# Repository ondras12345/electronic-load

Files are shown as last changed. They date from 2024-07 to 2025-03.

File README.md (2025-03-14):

# Electronic load
This repository contains hardware designs and firmware for my electronic load.

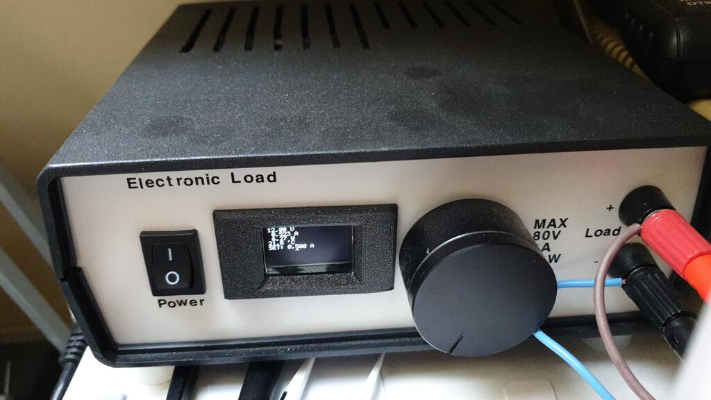
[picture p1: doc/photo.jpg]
DIY digitally controlled electronic load


## Hardware
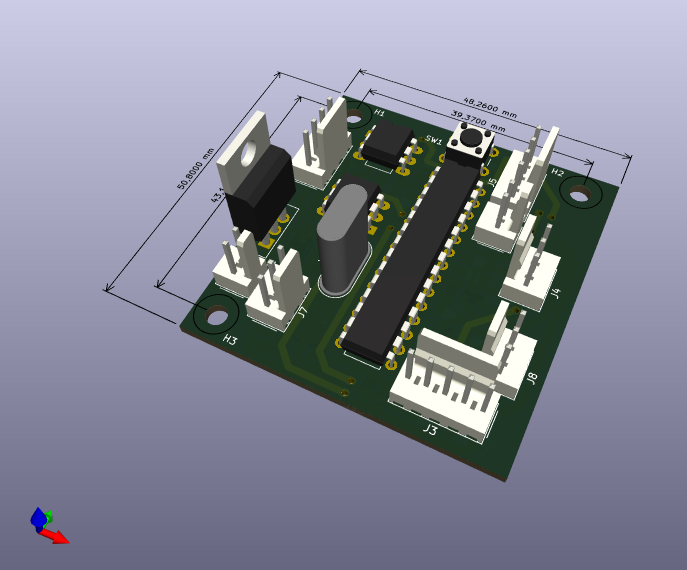
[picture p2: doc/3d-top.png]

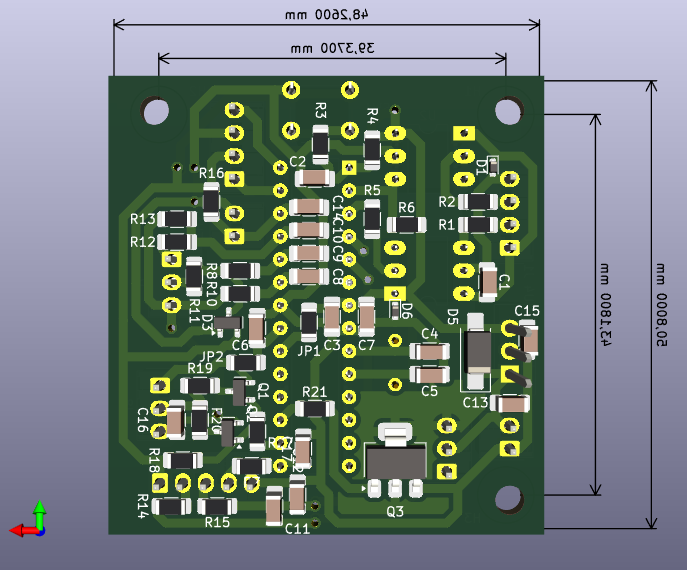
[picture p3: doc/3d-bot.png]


This project is based on an analog electronic load PCB from Aliexpress:
XHDZ-FZ-2g.
Originally, I just put it in a box and used it as-is with a 10-turn
potentiometer. However, then the pot failed, and I decided to upgrade it with
digital control. The control loop is still analog utilising the original
circuitry, but the reference signal is generated by a microcontroller instead
of the potentiometer.

My `electronic-load-controller` PCB contains an ATmega8 microcontroller,
a PWM DAC to generate the reference voltage, UART optoisolators for remote
control, and circuitry for measuring the load voltage and current.
It connects to the analog PCB via the original connectors with just one wire
needing to be soldered to a non-standard pad on the board.

The user interface consists of an SSD1306 OLED display and a rotary encoder.

Space for improvement: I didn't spend much time designing the user interface
and as a result, I had to use a small font that is hard to read from a
distance.

## Software
The firmware on the ATmega microcontroller performs several functions.
It measures the voltage across the load, the load current, calculates the
power loss and implements over-power protection, monitors the heatsink
temperature and controls the cooling fan.
It uses the DAC to generate the current setpoint signal for the analog board
based on the value set by the user via the rotary encoder,
and it implements a SCPI interface on the serial port for remote control
capability.

### SCPI commands
A text-based remote control interface is available on the serial port (9600
baud, 8N1).

The following table explains the individual command (`v` is a placeholder for
an integer argument).

| command | description |
|:---:|:---|
| `ISET v` | Set load current. E.g. `ISET 1000` sets the current to 1A. |
| `ISET?` | Get load current setpoint value in mA. |
| `IGAIN v` | Settings: set conversion coefficient for current measurement. |
| `IGAIN?` | Settings: get `IGAIN` value. |
| `VGAIN v` | Settings: set conversion coefficient for voltage measurement. |
| `VGAIN?` | Settings: get `VGAIN` value. |
| `SPGAIN v` | Settings: set conversion coefficient for current setpoint. |
| `SPGAIN?` | Settings: get `SPGAIN` value. |
| `SPOFF v` | Settings: set conversion offset for current setpoint. |
| `SPOFF?` | Settings: get `SPOFF` value. |
| `DUTY?` | Get PWM DAC duty cycle value. Useful for debugging. |
| `I?` | Get measured current in A. |
| `V?` | Get measured voltage in V. |
| `P?` | Get measured power in W. |
| `TEMP?` | Get heatsink temperature in degrees C. |
| `*BOOTLOADER` | Jump to bootloader to allow updating firmware. |
| `*SAV` | Save settings to EEPROM. |
| `*RST` | Reset the microcontroller. |

### Calibration
Calibration is performed using SCPI commands on the serial interface.
The goal is to make the load current and voltage readings accurate
and to make the current setpoint match the actual load current.

TODO document calibration procedure.

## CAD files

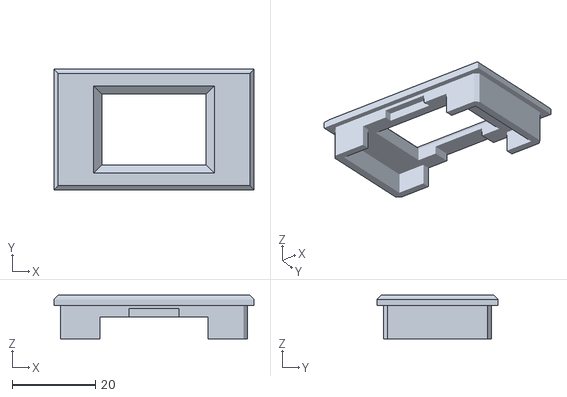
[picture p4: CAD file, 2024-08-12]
display-bracket-Part.stl
48.0 x 29.0 x 10.5

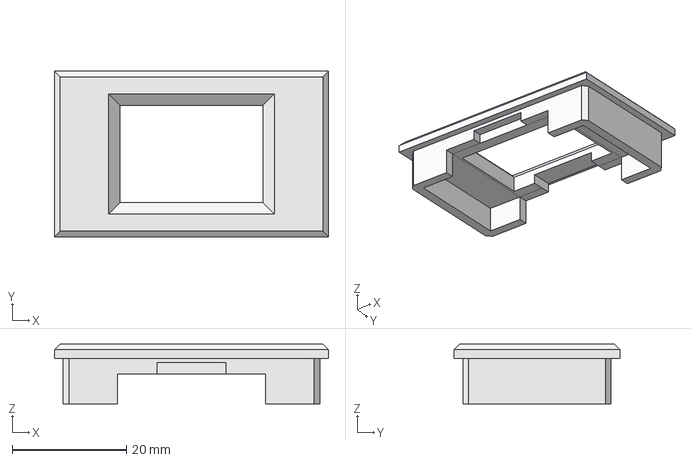
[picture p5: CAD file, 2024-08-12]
display-bracket.FCStd
48.0 x 29.0 x 10.5 mm

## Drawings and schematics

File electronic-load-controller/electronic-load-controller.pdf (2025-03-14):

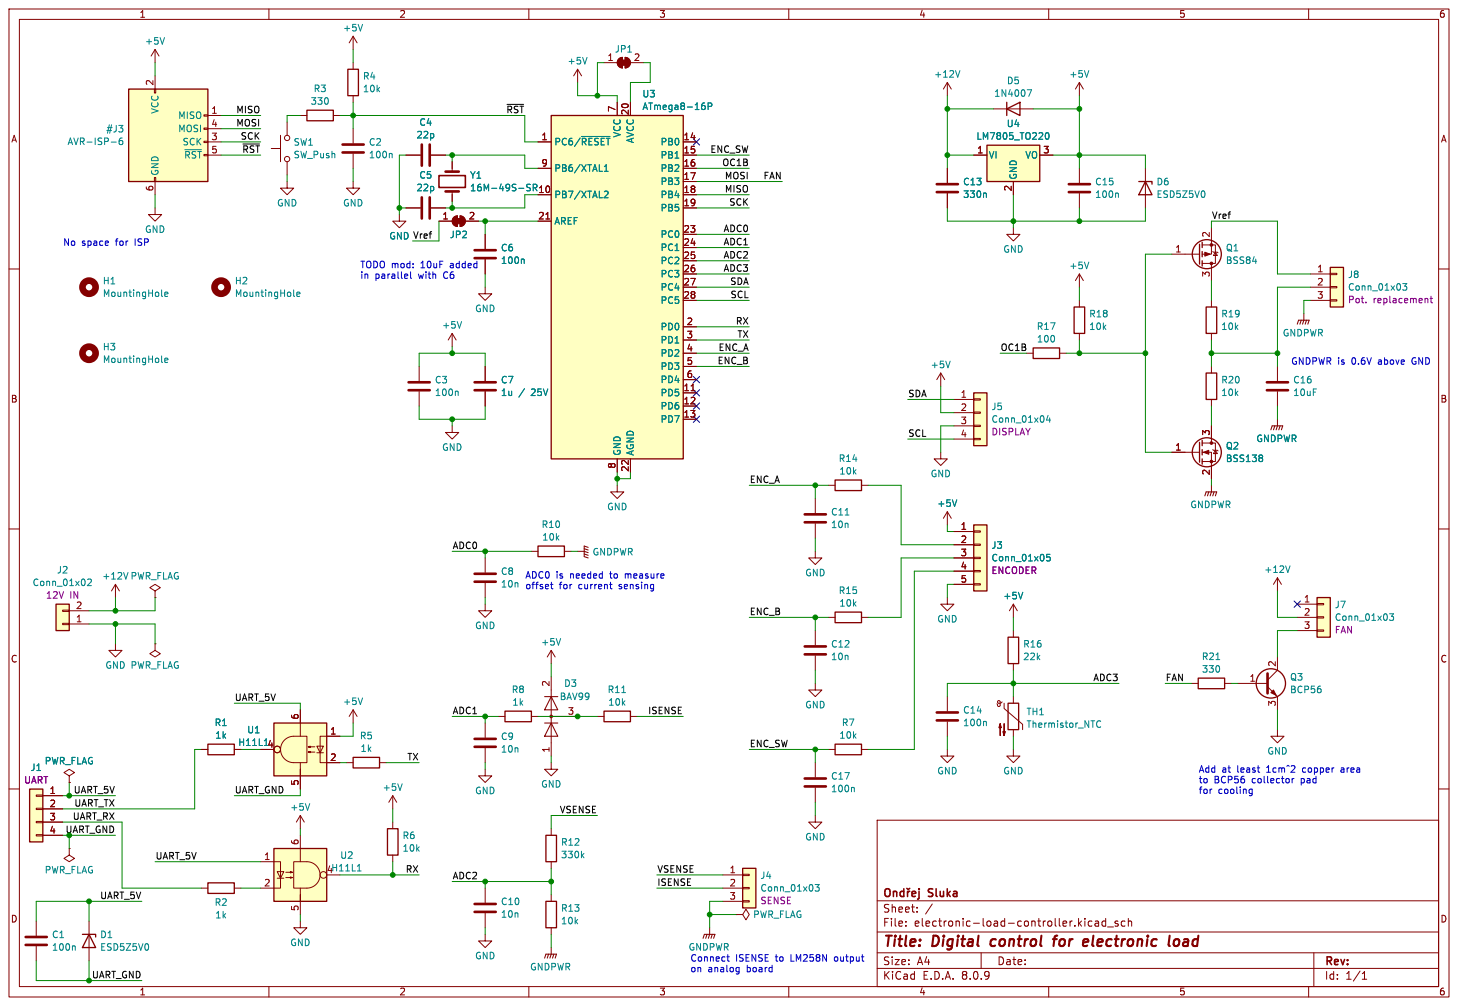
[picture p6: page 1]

2 SCK 3 MOSI 4 ~{RST}5 GND

SDA MISO MOSI SCK

File: electronic-load-controller.kicad_sch Sheet: / þÿOndYej Sluka

Id: 1/1 Title: Digital control for electronic load

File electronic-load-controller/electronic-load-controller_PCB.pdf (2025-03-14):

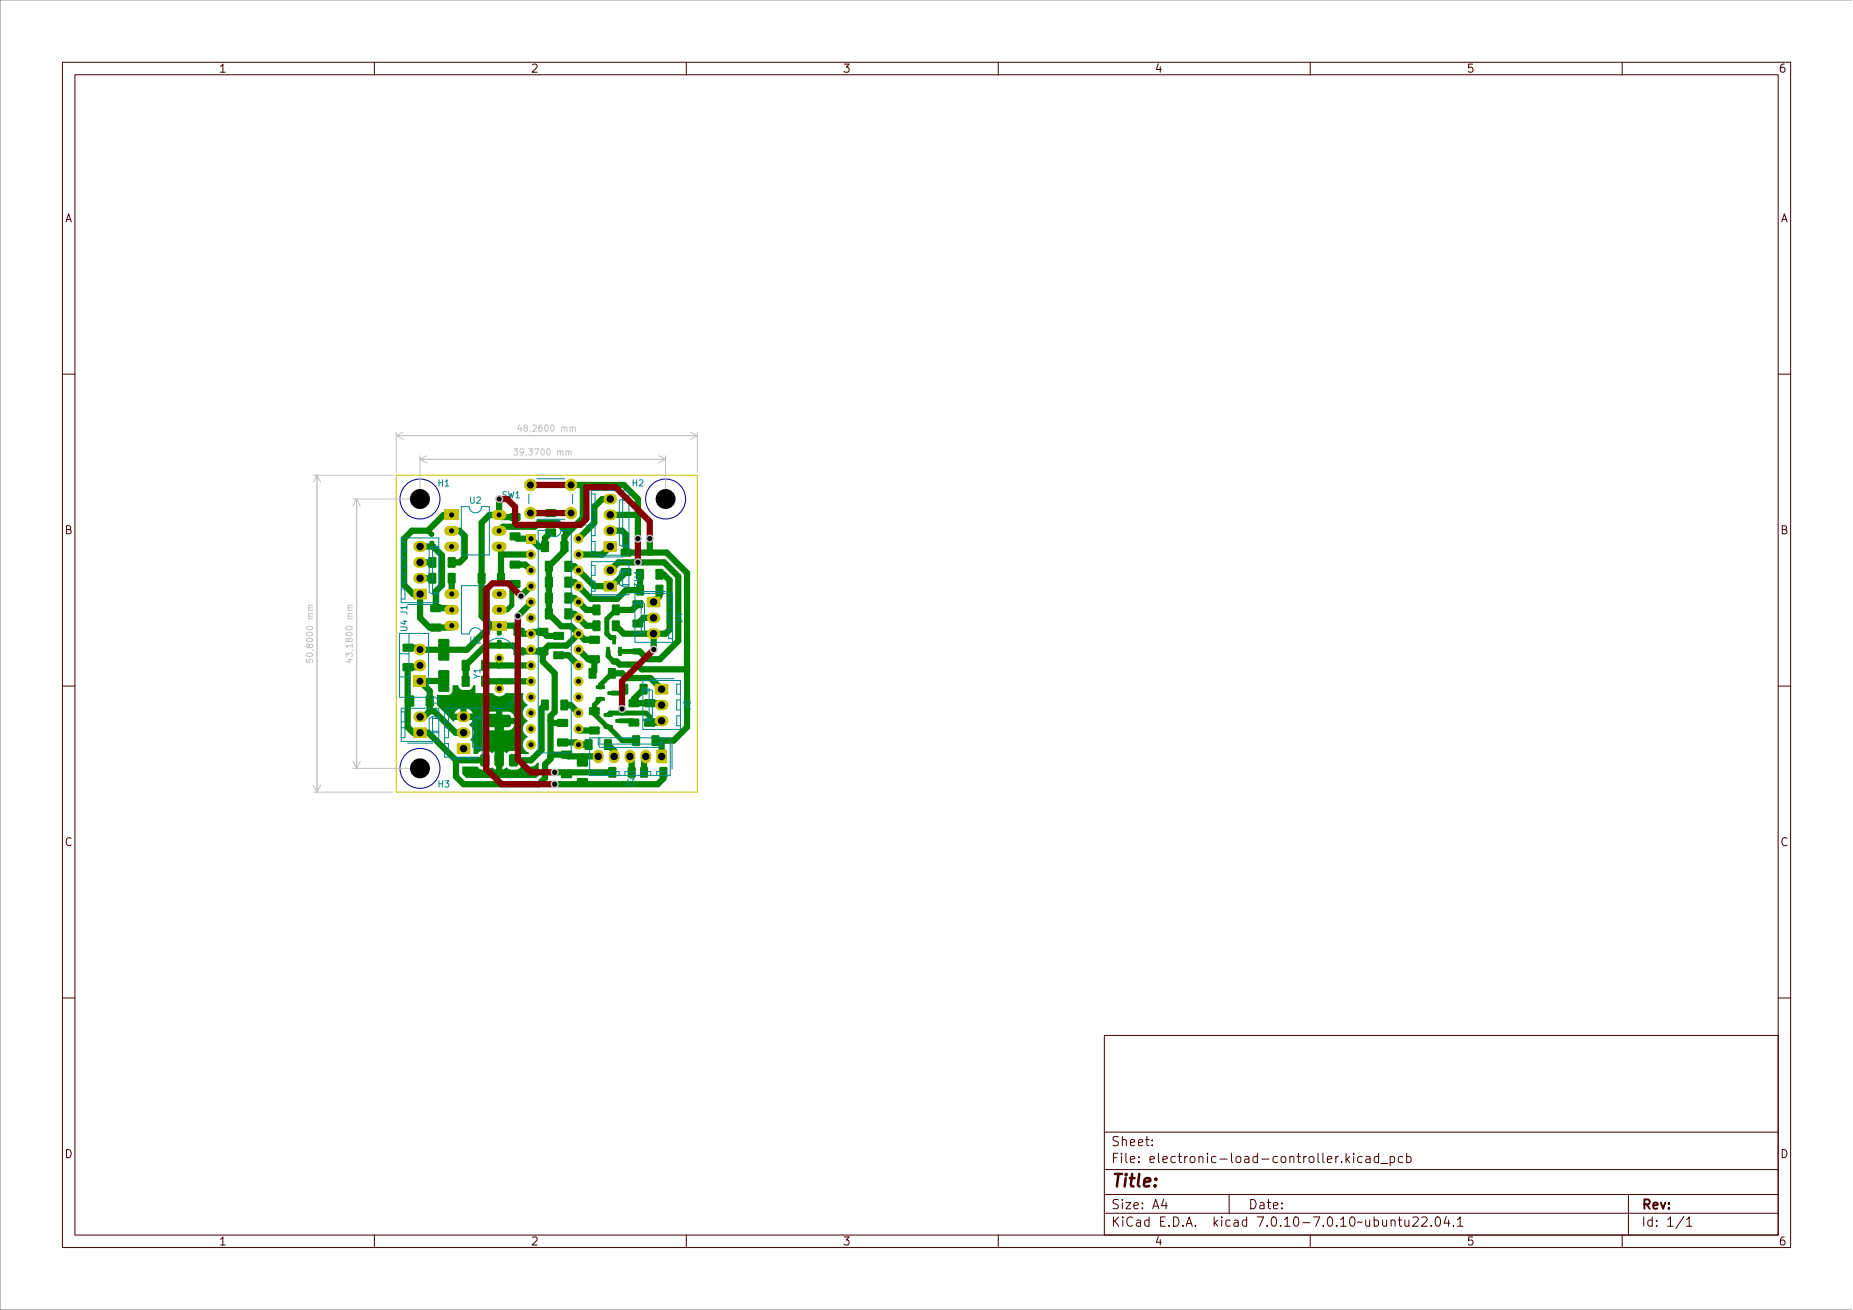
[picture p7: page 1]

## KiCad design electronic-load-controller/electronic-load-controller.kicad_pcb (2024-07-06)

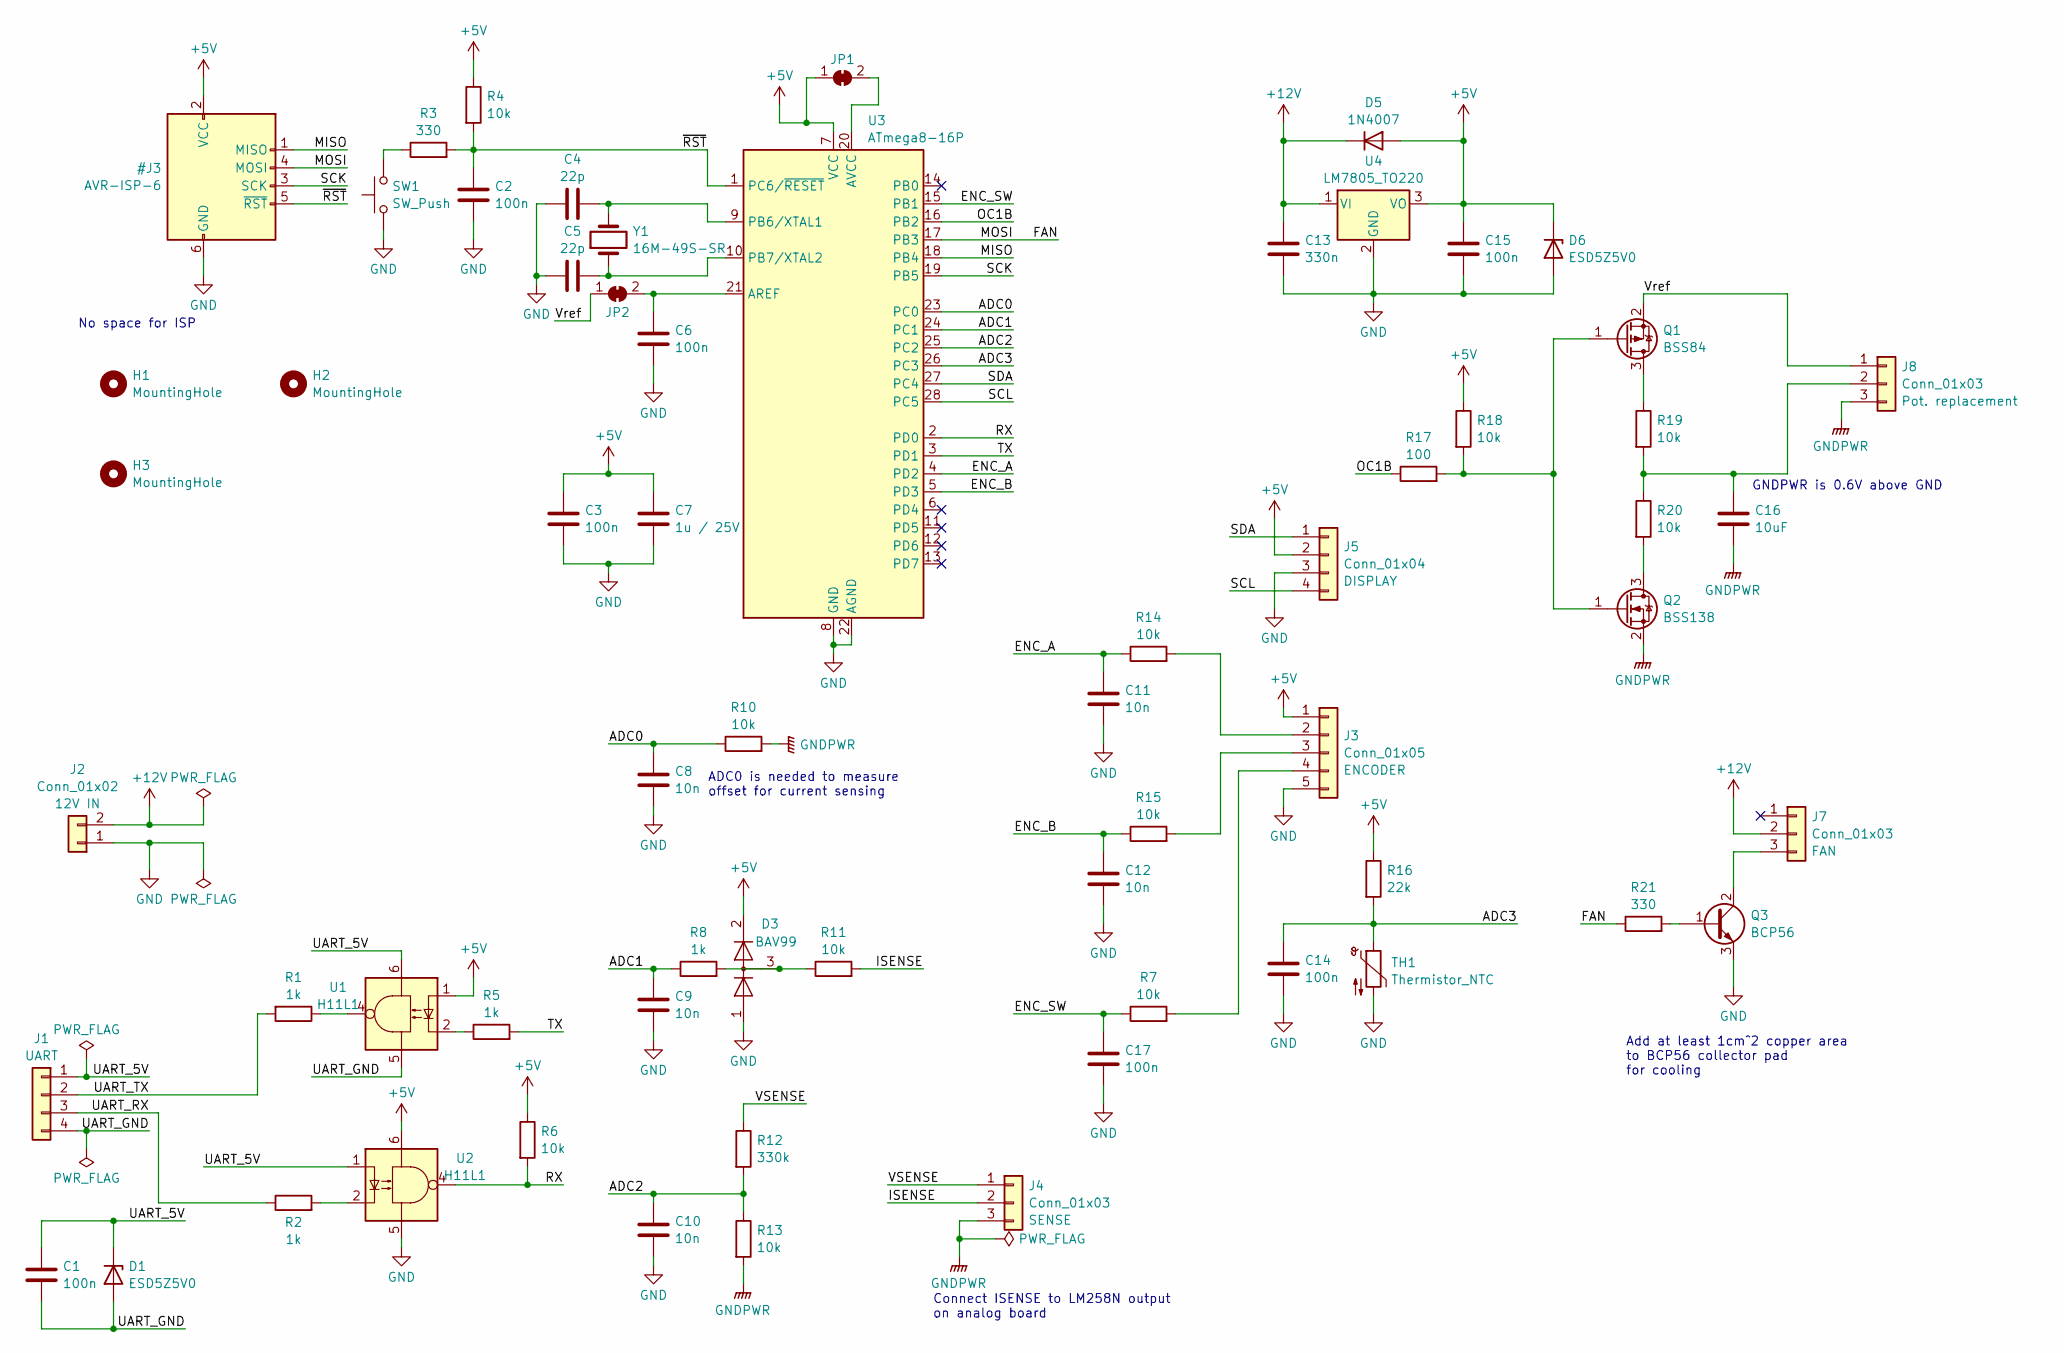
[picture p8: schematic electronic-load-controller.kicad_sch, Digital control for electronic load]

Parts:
C1, C2, C3, C6, C14, C15, C17: 100n; C_1206_3216Metric_Pad1.33x1.80mm_HandSolder
C4, C5: 22p; C_1206_3216Metric_Pad1.33x1.80mm_HandSolder
C7: 1u / 25V; C_1206_3216Metric_Pad1.33x1.80mm_HandSolder
C8, C9, C10, C11, C12: 10n; C_1206_3216Metric_Pad1.33x1.80mm_HandSolder
C13: 330n; C_1206_3216Metric_Pad1.33x1.80mm_HandSolder
C16: 10uF; C_1206_3216Metric_Pad1.33x1.80mm_HandSolder
D1, D6: ESD5Z5V0; D_SOD-523
D3: BAV99; SOT-23
D5: 1N4007; D_SMA_Handsoldering
H1, H2, H3: MountingHole; MountingHole_3.2mm_M3
J1, J5: Conn_01x04; Molex_KK-254_AE-6410-04A_1x04_P2.54mm_Vertical
J2: Conn_01x02; Molex_KK-254_AE-6410-02A_1x02_P2.54mm_Vertical
J3: Conn_01x05; Molex_KK-254_AE-6410-05A_1x05_P2.54mm_Vertical
J4, J7, J8: Conn_01x03; Molex_KK-254_AE-6410-03A_1x03_P2.54mm_Vertical
JP1, JP2: SolderJumper_2_Bridged; R_1206_3216Metric_Pad1.30x1.75mm_HandSolder
Q1: BSS84; SOT-23
Q2: BSS138; SOT-23
Q3: BCP56; SOT-223-3_TabPin2
R1, R2, R5, R8: 1k; R_1206_3216Metric_Pad1.30x1.75mm_HandSolder
R3, R21: 330; R_1206_3216Metric_Pad1.30x1.75mm_HandSolder
R4, R6, R7, R10, R11, R13, R14, R15, R18, R19, R20: 10k; R_1206_3216Metric_Pad1.30x1.75mm_HandSolder
R12: 330k; R_1206_3216Metric_Pad1.30x1.75mm_HandSolder
R16: 22k; R_1206_3216Metric_Pad1.30x1.75mm_HandSolder
R17: 100; R_1206_3216Metric_Pad1.30x1.75mm_HandSolder
SW1: SW_Push; SW_PUSH_6mm_H4.3mm
TH1: Thermistor_NTC; Molex_KK-254_AE-6410-02A_1x02_P2.54mm_Vertical
U1, U2: H11L1; DIP-6_W7.62mm_LongPads
U3: ATmega8-16P; DIP-28_W7.62mm
U4: LM7805_TO220; TO-220-3_Vertical
Y1: 16M-49S-SR; Crystal_HC49-U_Vertical

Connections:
+12V: C13.1, D5.1 (K), J2.2, J7.2, U4.1 (VI)
/ADC0: C8.1, R10.1, U3.23 (PC0)
/ADC1: C9.1, R8.1, U3.24 (PC1)
/ADC2: C10.1, R12.2, R13.1, U3.25 (PC2)
/ADC3: C14.1, R16.2, TH1.1, U3.26 (PC3)
/ENC_A: C11.1, R14.1, U3.4 (PD2)
/ENC_B: C12.1, R15.1, U3.5 (PD3)
/ENC_SW: C17.1, R7.1, U3.15 (PB1)
/ISENSE: J4.2, R11.2
/OC1B: R17.1, U3.16 (PB2)
/RX: R6.2, U2.4, U3.2 (PD0)
/SCL: J5.4, U3.28 (PC5)
/SDA: J5.1, U3.27 (PC4)
/TX: R5.2, U3.3 (PD1)
/UART_5V: C1.1, D1.1 (K), J1.1, U1.6, U2.1
/UART_GND: C1.2, D1.2 (A), J1.4, U1.5
/UART_RX: J1.3, R2.1
/UART_TX: J1.2, R1.2
/VSENSE: J4.1, R12.1
/Vref: J8.1, JP2.1 (A), Q1.2 (S)
GNDPWR: C16.2, J4.3, J8.3, Q2.2 (S), R10.2, R13.2
unnamed: D3.3 (K), R8.2, R11.1
unnamed: J3.2, R14.2
unnamed: J3.3, R15.2
unnamed: J3.4, R7.2
unnamed: J7.3, Q3.2 (C), Q3.4 (C)
unnamed: C16.1, J8.2, R19.2, R20.1
unnamed: JP1.2 (B), U3.20 (AVCC)
unnamed: C6.1, JP2.2 (B), U3.21 (AREF)
unnamed: Q1.3 (D), R19.1
unnamed: Q1.1 (G), Q2.1 (G), R17.2, R18.2
unnamed: Q2.3 (D), R20.2
unnamed: Q3.1 (B), R21.2
unnamed: R1.1, U1.4
unnamed: R2.2, U2.2
unnamed: R3.1, SW1.2
unnamed: R5.1, U1.2
unnamed: C4.2, U3.9 (PB6/XTAL1), Y1.2
unnamed: C5.2, U3.10 (PB7/XTAL2), Y1.1

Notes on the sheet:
Connect ISENSE to LM258N output on analog board
Add at least 1cm^2 copper area to BCP56 collector pad for cooling
No space for ISP
ADC0 is needed to measure offset for current sensing
GNDPWR is 0.6V above GND

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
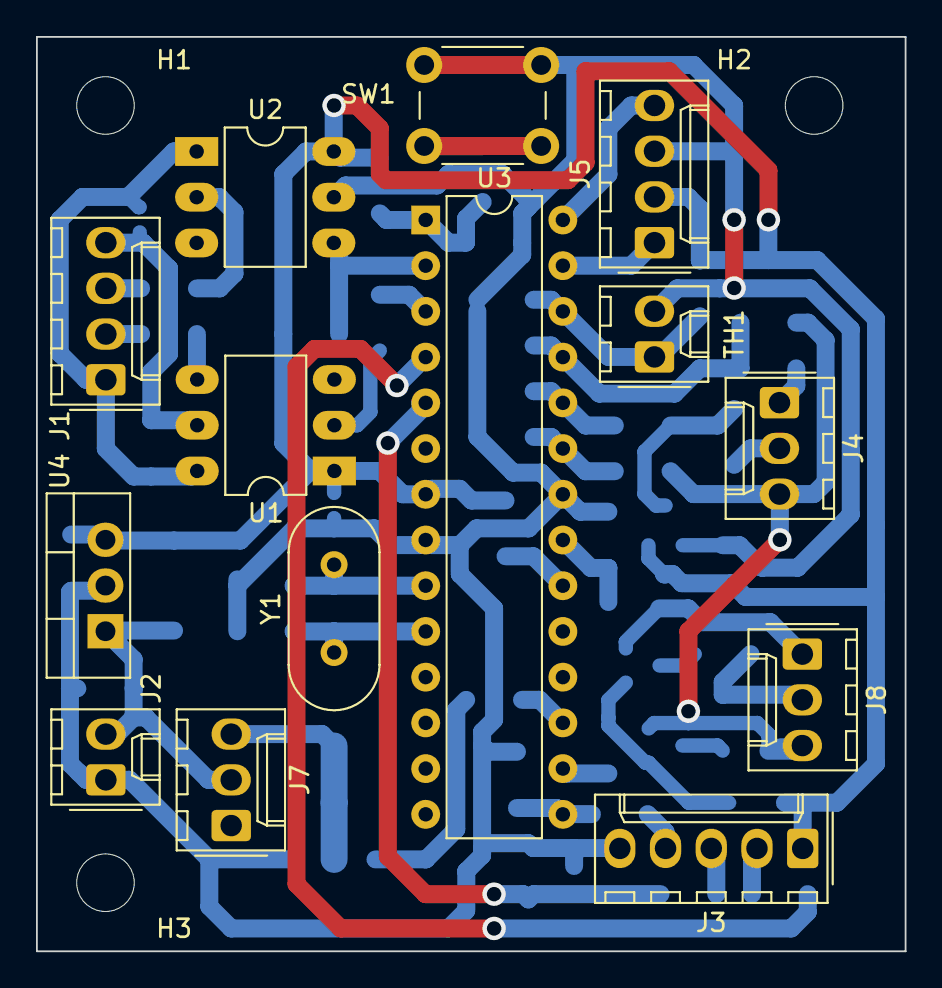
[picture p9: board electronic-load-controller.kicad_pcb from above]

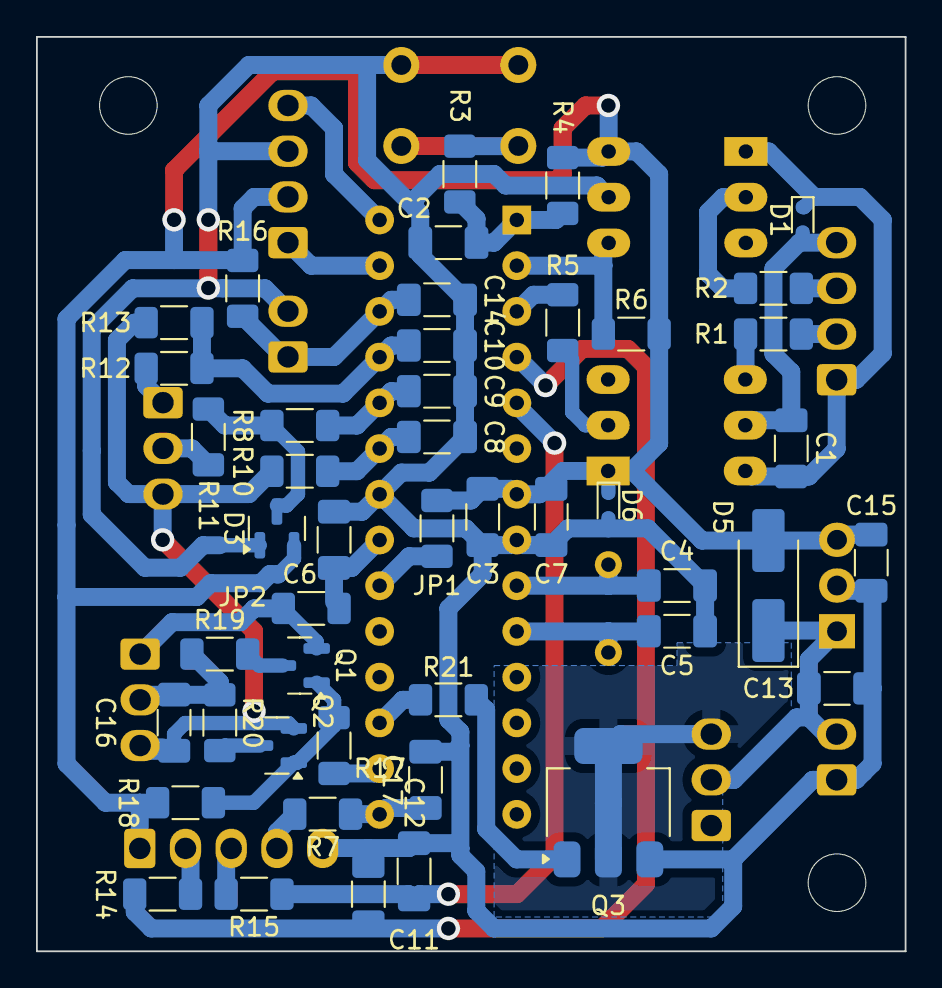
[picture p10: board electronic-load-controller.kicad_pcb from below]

Board: 2 copper layers, 48.3 x 50.8 mm, 63 parts (46 on the bottom side), 43 nets.

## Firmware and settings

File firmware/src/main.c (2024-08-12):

#include <stdbool.h>
#include <ctype.h>
#include <stdlib.h>
#include <avr/io.h>
#include <avr/interrupt.h>
#include <avr/pgmspace.h>
#include <avr/wdt.h>
#include <avr/eeprom.h>
#include <util/delay.h>
#include <util/atomic.h>
#include <math.h>

#include <lcd.h>
#include <gpio.h>
#include <serial.h>
#include "millis.h"
#include "serial_hash.h"

/*
PB1 .. ENC_SW
PB2 .. OC1B
PB3 .. FAN
PC0 .. ADC0 .. GNDPWR
PC1 .. ADC1 .. ISENSE
PC2 .. ADC2 .. VSENSE
PC3 .. ADC3 .. temperature
PC4 .. SDA
PC5 .. SCL

PD0 .. RX
PD1 .. TX
PD2 .. ENC_A
PD3 .. ENC_B
*/

#define PIN_ENCODER_SW  B, 1, 1 // PB1
#define PIN_PWM         B, 2, 2  // PB2
#define PIN_FAN         B, 3, 3  // PB3
#define PIN_ENCODER_AB  D, 3, 2  // PD3, PD2

// debounce times in ms
#define DEBOUNCE_ENCODER_SW 100U
// number of pulses per step
#define ENCODER_STEP 4

#define DISP_N_LINES 5

#define SETPOINT_MAX 8000U
#define POWER_MAX_W100 5000

// 12-bit PWM (frequency vs resolution tradeoff)
#define PWM_TOP 0x0FFF

#define ADC_GNDPWR 0
#define ADC_ISENSE 1
#define ADC_VSENSE 2
#define ADC_TEMPERATURE 3
#define ADC_NCHANNELS 4

// hypothetical ADC reading with 5 V on input
// AREF is 2.5V + diode drop (0.68V)
#define ADC_5V 1610U
#define ROOM_TEMPERATURE_KELVIN 298U  // 298.15
#define NTC_RDIV 22000U
#define NTC_BETA 3977U
#define NTC_RNOM 10000U

// fan temperature thresholds, 'C*10
#define TEMPERATURE_LOW 280
#define TEMPERATURE_HIGH 320

const int8_t ENCODER_MATRIX[16] = {0,1,-1,0,-1,0,0,1,1,0,0,-1,0,-1,1,0};

const uint16_t pow10_lut[] = {1, 10, 100, 1000, 10000};


volatile uint16_t ADC_values[ADC_NCHANNELS] = {0};
volatile bool ADC_complete = false;
volatile int8_t encoder_pulses = 0;
volatile bool encoder_pressed = false;
volatile bool encoder_fell = false;

uint16_t voltage_V100 = 0;  // in volts, stored * 100
uint16_t current_mA = 0;
uint16_t temperature_C10 = 0;  // 'C * 10
uint16_t power_W100 = 0;
uint8_t setpoint_digit = 2;  // which digit of setpoint is being edited
uint16_t setpoint_mA = 0;


typedef struct {
    // 2.5V ... 1023 ... 10A (roughly) ... 10000mA --> I_gain=9.77517106549365 -> 9775 ; seems to want 12775
    uint16_t I_gain1000;  // stored *1000
    // 2.5V ... 1023 ... 85V ... 8500 V100 --> V_gain=8.3088954056696 -> 8308 ; seems to want 10531
    uint16_t V_gain1000;  // stored *1000
    // full scale current in mA -> 10000 ; 10342
    uint16_t setpoint_gain;
    // offset added to OCR1B, ideally 0 ; 11
    uint8_t setpoint_offset;
} settings_t;

settings_t settings = { 0 };


static volatile millis_t mstimer = 0;


millis_t millis()
{
    millis_t ms;
    ATOMIC_BLOCK(ATOMIC_RESTORESTATE)
    {
        ms = mstimer;
    }
    return ms;
}


void millis_init(void)
{
    // prescaler 64
    TCCR0 = (1<<CS00) | (1<<CS01);
    // enable timer 0 overflow interrupt
    TIMSK |= (1<<TOIE0);
    TCNT0 = 0;
}


void adc_init()
{
    // init ADC
    // use AREF
    ADMUX = 0x00;
    ADCSRA = (1<<ADEN)  // enable ADC
           | (1<<ADIE)  // ADC interrupt enable
           | (1<<ADPS2) | (1<<ADPS1) | (1<<ADPS0)  // prescaler 128
           ;
    // first conversion will be started by TIMER0
}


void pwm_init()
{
    // set up timer1 for pwm on OC1B
    OCR1A = PWM_TOP;
    OCR1B = 0;  // duty
    // fast PWM mode, OC1B enabled inverting
    TCCR1A = (1<<COM1B1) | (1<<COM1B0) | (1<<WGM10) | (1<<WGM11);
    // clk/1
    TCCR1B = (1<<WGM12) | (1<<WGM13) | (1<<CS10);
    // PWM frequency is 16e6 / (PWM_TOP+1)
}


uint16_t NTC_temperature_C10(uint16_t ADC_reading)
{
    uint32_t R_thermistor = (uint32_t)(NTC_RDIV) * ADC_reading / (ADC_5V - ADC_reading);
    if (R_thermistor == 0) return 0;  // This shouldn't happen

    // Floating point division takes about 200B of FLASH space,
    // got rid of it by using log(a/b) = log(a) - log(b)
    uint16_t temperature_kelvin =
        ((uint32_t)(NTC_BETA) * ROOM_TEMPERATURE_KELVIN * 10) /
        (uint32_t)(NTC_BETA + ROOM_TEMPERATURE_KELVIN * (logf(R_thermistor) - logf(NTC_RNOM)));

    if (temperature_kelvin < 273*10) return 0;  // negative temperatures are not supported
    return temperature_kelvin - 273*10;
}


void format_current_mA(char * buf, size_t s)
{
    snprintf_P(buf, s,
        PSTR("%2u.%03u A"), current_mA / 1000, current_mA % 1000
    );
}


void format_voltage_V100(char * buf, size_t s)
{
    snprintf_P(buf, s,
            PSTR("%2u.%02u V"), voltage_V100 / 100, voltage_V100 % 100
    );
}


void format_power_W100(char * buf, size_t s)
{
    snprintf_P(buf, s,
            PSTR("%2u.%02u W"), power_W100 / 100, power_W100 % 100
    );
}


void serial_nl()
{
    serial_puts_P(PSTR("\r\n"));
}


void serial_parser()
{
    bool complete = false;
    static char buf[50 + sizeof '\0'];
    static uint8_t wi = 0;

    while (serial_available() && !complete)
    {
        char c = serial_read();
        buf[wi] = c;
        if (c == '\r' || c == '\n')
        {
            if (wi != 0)
            {
                buf[wi] = '\0';  // overwrite that newline
                complete = true;
                wi = 0;
            }
        }
        else
        {
            if (wi < sizeof(buf)-1)
            {
                wi++;
            }
            else
            {
                serial_puts_P(PSTR("E: too long\r\n"));
                wi = 0;
            }
        }
    }

    if (!complete) return;
    const char * number_str;
    for (number_str = buf; *number_str && !isdigit(*number_str); number_str++);

    // list of hashes corresponding to commands can be generated by make test
    long v = atol(number_str);  // temp variable for atol, used by some cases
    if (v < 0) v = 0;
    switch (serial_hash(buf))
    {
        case 45274:  // "ISET "
            // ISET 1000 : set current to 1A
            setpoint_mA = v;
            if (setpoint_mA > SETPOINT_MAX) setpoint_mA = SETPOINT_MAX;
            break;

        case 19405:  // "IGAIN "
            settings.I_gain1000 = v;
            break;

        case 23546:  // "VGAIN "
            settings.V_gain1000 = v;
            break;

        case 45927:  // "SPGAIN "
            settings.setpoint_gain = v;
            break;

        case 24099:  // "SPOFF "
            settings.setpoint_offset = v;
            break;

        case 45305:  // "ISET?"
            snprintf_P(buf, sizeof buf,
                    PSTR("%u.%03u A\r\n"), setpoint_mA / 1000, setpoint_mA % 1000
            );
            serial_puts(buf);
            break;

        case 36778:  // "DUTY?"
            serial_putuint(OCR1B);
            serial_nl();
            break;

        case 29677:  // "I?"
            format_current_mA(buf, sizeof buf);
            serial_puts(buf);
            serial_nl();
            break;

        case 30106:  // "V?"
            format_voltage_V100(buf, sizeof buf);
            serial_puts(buf);
            serial_nl();
            break;

        case 29908:  // "P?"
            format_power_W100(buf, sizeof buf);
            serial_puts(buf);
            serial_nl();
            break;

        case 12986:  // "TEMP?"
            snprintf_P(buf, sizeof buf,
                    PSTR("%u.%u degC\r\n"), temperature_C10 / 10, temperature_C10 % 10
            );
            serial_puts(buf);
            break;

        case 19436:  // "IGAIN?"
            serial_putuint(settings.I_gain1000);
            serial_nl();
            break;

        case 23577:  // "VGAIN?"
            serial_putuint(settings.V_gain1000);
            serial_nl();
            break;

        case 45958:  // "SPGAIN?"
            serial_putuint(settings.setpoint_gain);
            serial_nl();
            break;

        case 24130:  // "SPOFF?"
            serial_putuint(settings.setpoint_offset);
            serial_nl();
            break;

        case 56794:  // "*BOOTLOADER"
        {
            OCR1B = 0;  // duty
            gpio_set(PIN_FAN);

            _delay_ms(200);

            // https://arduino.stackexchange.com/questions/77226/jumping-to-bootloader-from-application-code-in-atmega328p
            // we are using Optiboot 8
            typedef void (*bootloader_jump_t)();
            const bootloader_jump_t bootloader_jump = (bootloader_jump_t)((FLASHEND-511)>>1);
            bootloader_jump();
        }
            break;

        case 33081:  // "*SAV"
            // save settings to EEPROM
            eeprom_update_block(&settings, 0, sizeof settings);
            break;

        case 32584:  // "*RST"
            OCR1B = 0;  // duty
            wdt_enable(WDTO_15MS);
            for (;;);
            break;

        default:
            serial_puts_P(PSTR("E: invalid cmd\r\n"));
            break;
    }
}


/// return true if refresh is done
bool disp_handler(void)
{
    static uint8_t line = 0;

    lcd_gotoxy(0, line);
    char buf[16];

    switch (line)
    {
        case 0:
            format_voltage_V100(buf, sizeof buf);
            break;
        case 1:
            format_current_mA(buf, sizeof buf);
            break;
        case 2:
            format_power_W100(buf, sizeof buf);
            break;
        case 3:
            snprintf_P(buf, sizeof buf,
                    PSTR("%2u.%u 'C"), temperature_C10 / 10, temperature_C10 % 10
            );
            break;
        case 4:
            snprintf_P(buf, sizeof buf,
                    PSTR("SET: %u.%03u A"), setpoint_mA / 1000, setpoint_mA % 1000
            );
            break;
        case 5:
        {
            // show cursor position
            //                 "SET: 1.235 A"
            strcpy_P(buf, PSTR("          "));
            uint8_t cpos = 9 - setpoint_digit;
            // handle decimal point
            if (cpos <= 6) cpos--;
            buf[cpos] = '^';
        }
            break;

        default:
            // this should never happen
            buf[0] = 0;
            break;
    }

    lcd_puts(buf);


    line = (line + 1) % (DISP_N_LINES+1);
    return line == 0;  // true if done
}


int main(void)
{
    gpio_conf(PIN_PWM, OUTPUT, 1);  // start with 0 current
    gpio_conf(PIN_FAN, OUTPUT, 1);  // start with fan on
    // inputs - nopullup is default
    //gpio_conf(PIN_ENCODER_AB, INPUT, NOPULLUP);
    //gpio_conf(PIN_ENCODER_SW, INPUT, NOPULLUP);

    // enable INT0, INT1 for encoder
    MCUCR |= (1<<ISC00) | (1<<ISC10);  // any logical change
    GICR |= (1<<INT0) | (1<<INT1);  // enable

    pwm_init();
    millis_init();
    adc_init();
    serial_init9600();
    sei();
    // read settings from EEPROM
    eeprom_read_block(&settings, 0, sizeof settings);
    wdt_enable(WDTO_500MS);
    wdt_reset();
    lcd_init(LCD_DISP_ON);
    lcd_puts_p(PSTR("boot"));

    for (;;)
    {
        serial_parser();

        // set duty
        uint16_t d = (uint32_t)(setpoint_mA) * PWM_TOP / settings.setpoint_gain + settings.setpoint_offset;
        OCR1B = (d < PWM_TOP) ? d : PWM_TOP;

        // control fan
        static bool fan = true;
        uint16_t fan_thres = fan ? TEMPERATURE_LOW : TEMPERATURE_HIGH;
        // if NTC is disconnected, it might report low temperature (or 0 on error)
        fan = (temperature_C10 > fan_thres || temperature_C10 < 10);
        if (fan) gpio_set(PIN_FAN);
        else gpio_clr(PIN_FAN);

        if (ADC_complete)
        {
            uint16_t vals[ADC_NCHANNELS];
            ATOMIC_BLOCK(ATOMIC_FORCEON)
            {
                for (uint8_t i = 0; i < ADC_NCHANNELS; i++)
                    vals[i] = ADC_values[i];
                ADC_complete = false;
            }
            // remove GNDPWR offset
            uint16_t off = vals[ADC_GNDPWR];
#define rmoff(val) val = (off > val) ? 0 : (val-off)
            rmoff(vals[ADC_VSENSE]);
            rmoff(vals[ADC_ISENSE]);
#undef rmoff

            const uint16_t V_max = (settings.V_gain1000 == 0) ? 0 : 65535000UL / settings.V_gain1000;
            if (vals[ADC_VSENSE] >= V_max) voltage_V100 = -1;
            else voltage_V100 = (uint32_t)(vals[ADC_VSENSE]) * settings.V_gain1000 / 1000U;

            const uint16_t I_max = (settings.I_gain1000 == 0) ? 0 : 65535000UL / settings.I_gain1000;
            if (vals[ADC_ISENSE] >= I_max) current_mA = -1;
            else current_mA = (uint32_t)(vals[ADC_ISENSE]) * settings.I_gain1000 / 1000U;

            power_W100 = ((uint32_t)(voltage_V100) * current_mA) / 1000U;

            // limit power to POWER_MAX
            uint16_t Imax_mA = POWER_MAX_W100*1000UL / voltage_V100;
            if (setpoint_mA > Imax_mA) setpoint_mA = Imax_mA;

            temperature_C10 = NTC_temperature_C10(vals[ADC_TEMPERATURE]);
        }

        millis_t now = millis();
        bool force_refresh = false;
        // handle encoder
        if (encoder_fell)
        {
            encoder_fell = false;
            setpoint_digit++;
            if (setpoint_digit > 3) setpoint_digit = 0;
            force_refresh = true;
        }

        int8_t steps = 0;
        ATOMIC_BLOCK(ATOMIC_RESTORESTATE)
        {
            while (encoder_pulses >= ENCODER_STEP)
            {
                encoder_pulses -= ENCODER_STEP;
                steps++;
            }
            while (encoder_pulses <= -ENCODER_STEP)
            {
                encoder_pulses += ENCODER_STEP;
                steps--;
            }
        }
        static millis_t enc_prev_ms = 0;
        if (now - enc_prev_ms >= 1000U)
        {
            enc_prev_ms = now;
            // do not get stuck at number smaller than ENCODER_STEP
            encoder_pulses = 0;
        }
        if (setpoint_digit >= sizeof(pow10_lut)/sizeof(pow10_lut[0]))
            setpoint_digit = 0;
        if (steps != 0)
        {
            force_refresh = true;
            enc_prev_ms = now;
        }
        // quickly disable load by turning left while holding button
        if (encoder_pressed && steps < 0) setpoint_mA = 0;
        uint16_t prev = setpoint_mA;
        setpoint_mA += steps * pow10_lut[setpoint_digit];
        if (steps < 0 && setpoint_mA > prev) setpoint_mA = 0;
        if (setpoint_mA > SETPOINT_MAX) setpoint_mA = SETPOINT_MAX;

        static millis_t disp_prev_ms = 0;
        static bool disp_in_progress = false;
        if (now - disp_prev_ms >= 250U || force_refresh || disp_in_progress)
        {
            disp_prev_ms = now;
            disp_in_progress = !disp_handler();
        }

        wdt_reset();
    }

    return 0;
}


ISR(TIMER0_OVF_vect)
{
    mstimer++;
    // compensate - get interrupt every ms instead of every 1.024 ms
    // TODO is this correct?
    TCNT0 += 6;

    // encoder button debounce
    static uint8_t integrator = 0;
    if (gpio_tst(PIN_ENCODER_SW))
    {
        if (integrator < DEBOUNCE_ENCODER_SW) integrator++;
    }
    else
    {
        if (integrator > 0) integrator--;
    }
    bool prev = encoder_pressed;
    if (integrator == 0) encoder_pressed = true;
    if (integrator >= DEBOUNCE_ENCODER_SW) encoder_pressed = false;
    if (encoder_pressed && !prev) encoder_fell = true;

    // ignoring ADC_complete, we just hope loop() managed to read the values in
    // time

    // Start new conversion
    // at channel 0 (set either by ADC_init or ISR(ADC_vect)
    ADCSRA |= (1<<ADSC);
}


ISR(ADC_vect)
{
    uint8_t t = ADMUX;
    // warning: this does not use ADC_NCHANNELS
    uint8_t channel = t & 0x03;
    uint8_t next_channel = ((channel+1) & 0x03);

    // ADCL must be read first
    uint8_t L = ADCL;
    uint8_t H = ADCH;
    uint16_t sample = (H << 8) | L;

    // apply lowpass filter
    // https://docs.openenergymonitor.org/electricity-monitoring/ctac/digital-filters-for-offset-removal.html
    // this determines lowpass filter time constant, see test_DCfilter
    #define FILTERSHIFT 8
    #define FILTERROUNDING (1<<(FILTERSHIFT-1))
    static uint32_t foffset[ADC_NCHANNELS] = { 0 };
    int16_t offset = (foffset[channel] + FILTERROUNDING) >> FILTERSHIFT;
    foffset[channel] += (int16_t)sample - offset;
    ADC_values[channel] = offset;

    // advance to next channel
    ADMUX = (t & 0xF0) | next_channel;

    if (next_channel == 0) ADC_complete = true;
    // start new conversion
    else ADCSRA |= (1<<ADSC);
}


ISR(INT1_vect, ISR_ALIASOF(INT0_vect));

ISR(INT0_vect)
{
    static uint8_t state = 0x03;
    state = ((state << 2) | gpio_rd(PIN, PIN_ENCODER_AB)) & 0x0F;
    encoder_pulses += ENCODER_MATRIX[state];
}

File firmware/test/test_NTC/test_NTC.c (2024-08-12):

#include <unity.h>
#include <stdio.h>
#include <stdint.h>
#include <math.h>

// hypothetical ADC reading with 5 V on input
#define ADC_5V 1610U
#define ROOM_TEMPERATURE_KELVIN 298U  // 298.15
#define NTC_RDIV 22000U
#define NTC_BETA 3977U
#define NTC_RNOM 10000U


uint16_t NTC_temperature_C10(uint16_t ADC_reading)
{
    printf("ADC_reading = %u\n", ADC_reading);
    uint32_t R_thermistor = (uint32_t)(NTC_RDIV) * ADC_reading / (ADC_5V - ADC_reading);
    if (R_thermistor == 0) return 0;  // This shouldn't happen
    printf("R_thermistor = %u\n", R_thermistor);

    // Floating point division takes about 200B of FLASH space,
    // got rid of it by using log(a/b) = log(a) - log(b)
    uint16_t temperature_kelvin =
        ((uint32_t)(NTC_BETA) * ROOM_TEMPERATURE_KELVIN * 10) /
        (uint32_t)(NTC_BETA + ROOM_TEMPERATURE_KELVIN * (logf(R_thermistor) - logf(NTC_RNOM)));
    printf("kelvin = %u\n", temperature_kelvin);

    if (temperature_kelvin < 273*10) return 0;  // negative temperatures are not supported
    return temperature_kelvin - 273*10;
}




void test_NTC()
{
    // measured: 20kOhm 2.424V
    TEST_ASSERT_EQUAL_UINT16(96, NTC_temperature_C10(2.424 / 5 * ADC_5V));
    // measured: 8kOhm 1.359V
    TEST_ASSERT_EQUAL_UINT16(295, NTC_temperature_C10(1.359 / 5 * ADC_5V));
    TEST_ASSERT_EQUAL_UINT16(0, NTC_temperature_C10(0));
}


int runUnityTests(void)
{
    UNITY_BEGIN();
    RUN_TEST(test_NTC);


    return UNITY_END();
}


int main(void)
{
    return runUnityTests();
}

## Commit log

2024-07-06 Add project files
    [electronic-load-controller.kicad_pcb, electronic-load-controller.kicad_sch]
2024-07-06 Increase I2C clock frequency
2024-07-06 Handle encoder
2024-07-06 Implement UART interface
2024-07-07 Fix incorrect use of serial_puts_P
    [main.c]
2024-07-08 Reduce I2C frequency to prevent display problems
    [main.c]
2024-07-08 Fix encoder interrupts not enabled
    [main.c]
2024-07-08 Only write encoder_pulses in ATOMIC_BLOCK
2024-07-08 Fix upload via bootloader
    [main.c]
2024-07-08 Fix encoder ignoring first step
    [main.c]
2024-07-10 Reduce ADC sampling frequency
2024-07-10 Reduce width of millis_t to save flash space
2024-07-10 Display power
2024-07-10 Allow querying power via UART
2024-07-10 Remove useless UPTIME? command
    millis_t can only count up to 65 seconds
2024-07-12 Add lowpass filter to ADC
    [electronic-load-controller.kicad_sch]
2024-07-13 Fix NTC temperature measurement
    [main.c]
2024-07-13 Increase I2C clock speed
2024-07-14 Update display one line at a time
    (All following builds were done with experimental power limit patch)
    before:
    RAM: [=== ] 26.5% (used 271 bytes from 1024 bytes)
    Flash: [==========] 98.4% (used 7556 bytes from 7680 bytes)
    after (all at once):
    RAM: [=== ] 26.6% (used 272 bytes from 1024 bytes)
    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
2024-07-24 Calibrate current setpoint
    Refactoring was needed to fit in FLASH
2024-08-12 Limit power
2024-08-12 Add display bracket design
    [display-bracket-Part.stl, display-bracket.FCStd]
2025-03-14 Add KiCAD PDF outputs
    [electronic-load-controller.kicad_sch]
